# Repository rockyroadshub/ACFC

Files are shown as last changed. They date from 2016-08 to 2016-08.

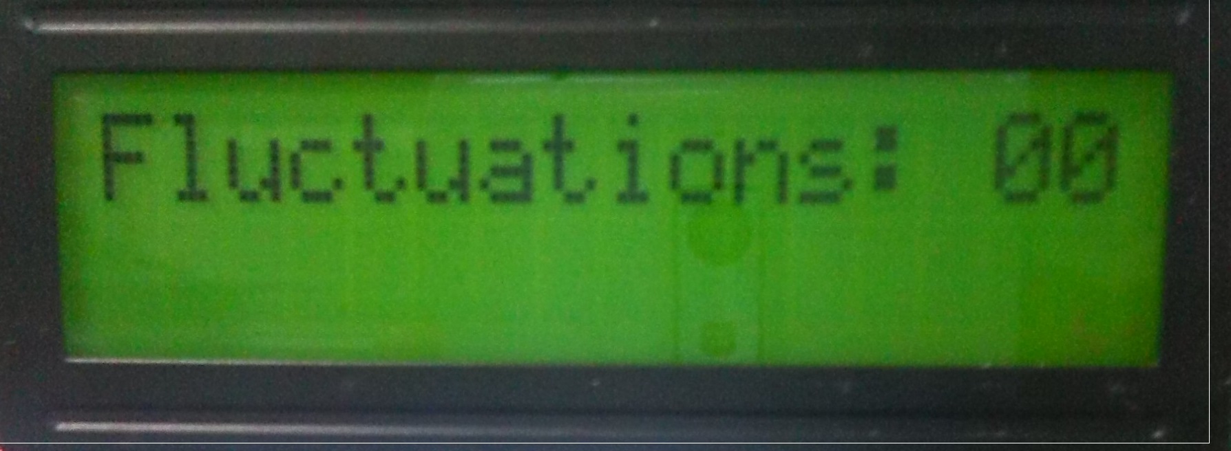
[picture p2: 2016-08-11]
Essentials/Features/Total Fluctuation Display.jpg

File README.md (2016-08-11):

# ACFC
ACFC Timer and Counter is a micro-controller based project that gets the time and 
counts the number of power outages occurred.
-------------------------------------------------------------------------------------------------
PROJECT :   AC Fluctuation TImer and Counter
VERSION :   1.0.0
FILE    :   ACFC_MAIN.ino
AUTHOR  :   Arnell Christoper D. Dalid
COMPANY :   PLDT Makati - South Core Net--Field Force 3 (PEMS) [PHILS]
PURPOSE :   [Internship Project] - Counts and save the time duration of a fluctuation occured
HISTORY :   [Created - 1.0.0]    - November 25, 2014
            [Finalized]          - March 3, 2015 (Source Code)
-------------------------------------------------------------------------------------------------          
FOLDERS										REMARKS

I.	Essentials								Important files needed to create project
	1. Features
	2. Model
	3. Others
	4. PCB
	5. Parts List

II.	Libraries								Libraries needed for the project's source code
	1. MemoryFree
	2. Misc
	3. StopWatch
	4. Time

III.Manuals									Manuals for different components used in the
	1. Source File							project
	2. ACFC Manual
	3. ACFC Report
	4. ATmega
	5. Gizduino Compatibility
	6. Gizduino Installation Guide
	7. LCD 16x2 SC162A3 Datasheet
	8. OMRON MY Relay Datasheet
	9. PCB Etching

IV.	Peripherals								Programs used for the project
	1. gizDuinoPatch
	2. PL2303 win7 installer
	3. arduino-1.0.6-windows

V.	Source Code								Code to be uploaded in the Gizduino ATmega
											microcontroller
-------------------------------------------------------------------------------------------------                                   
Other Softwares used: (freewares)

NAME		VERSION		DOWNLOAD LINK

Blender		2.73		http://www.blender.org/download/
Fritzing	0.9.1b		http://www.fritzing.org/download/

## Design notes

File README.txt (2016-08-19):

# ACFC
Copyright 2016 Arnell Christoper D. Dalid

ACFC Timer and Counter is a micro-controller based project that gets the time and 
counts the number of power outages occurred.

Licensed under GNU General Public License v3.0 (see license.txt)
-------------------------------------------------------------------------------------------------
PROJECT :   AC Fluctuation TImer and Counter
VERSION :   1.0.0
FILE    :   ACFC_MAIN.ino
AUTHOR  :   Arnell Christoper D. Dalid
COMPANY :   PLDT Makati - South Core Net--Field Force 3 (PEMS) [PHILS]
PURPOSE :   [Internship Project] - Counts and save the time duration of a fluctuation occured
HISTORY :   [Created - 1.0.0]    - November 25, 2014
            [Finalized]          - March 3, 2015 (Source Code)
-------------------------------------------------------------------------------------------------          
FOLDERS						REMARKS

I.	Essentials				Important files needed to create project
	1. Features
	2. Model
	3. Others
	4. PCB
	5. Parts List

II.	Libraries				Libraries needed for the project's source code
	1. MemoryFree
	2. Misc
	3. StopWatch
	4. Time

III.Manuals					Manuals for different components used in the
	1. Source File				project
	2. ACFC Manual
	3. ATmega
	4. Gizduino Compatibility
	5. Gizduino Installation Guide
	6. LCD 16x2 SC162A3 Datasheet
	7. OMRON MY Relay Datasheet
	8. PCB Etching

IV.	Peripherals				Programs used for the project
	1. gizDuinoPatch
	2. PL2303 win7 installer

V.	Source Code				Code to be uploaded in the Gizduino ATmega
						microcontroller
-------------------------------------------------------------------------------------------------                                   
Other Softwares used: (freewares)

NAME		VERSION		WEBSITE

Blender		2.73		http://www.blender.org
Fritzing	0.9.1b		http://www.fritzing.org
Arduino IDE	1.0.6		http://www.arduino.cc

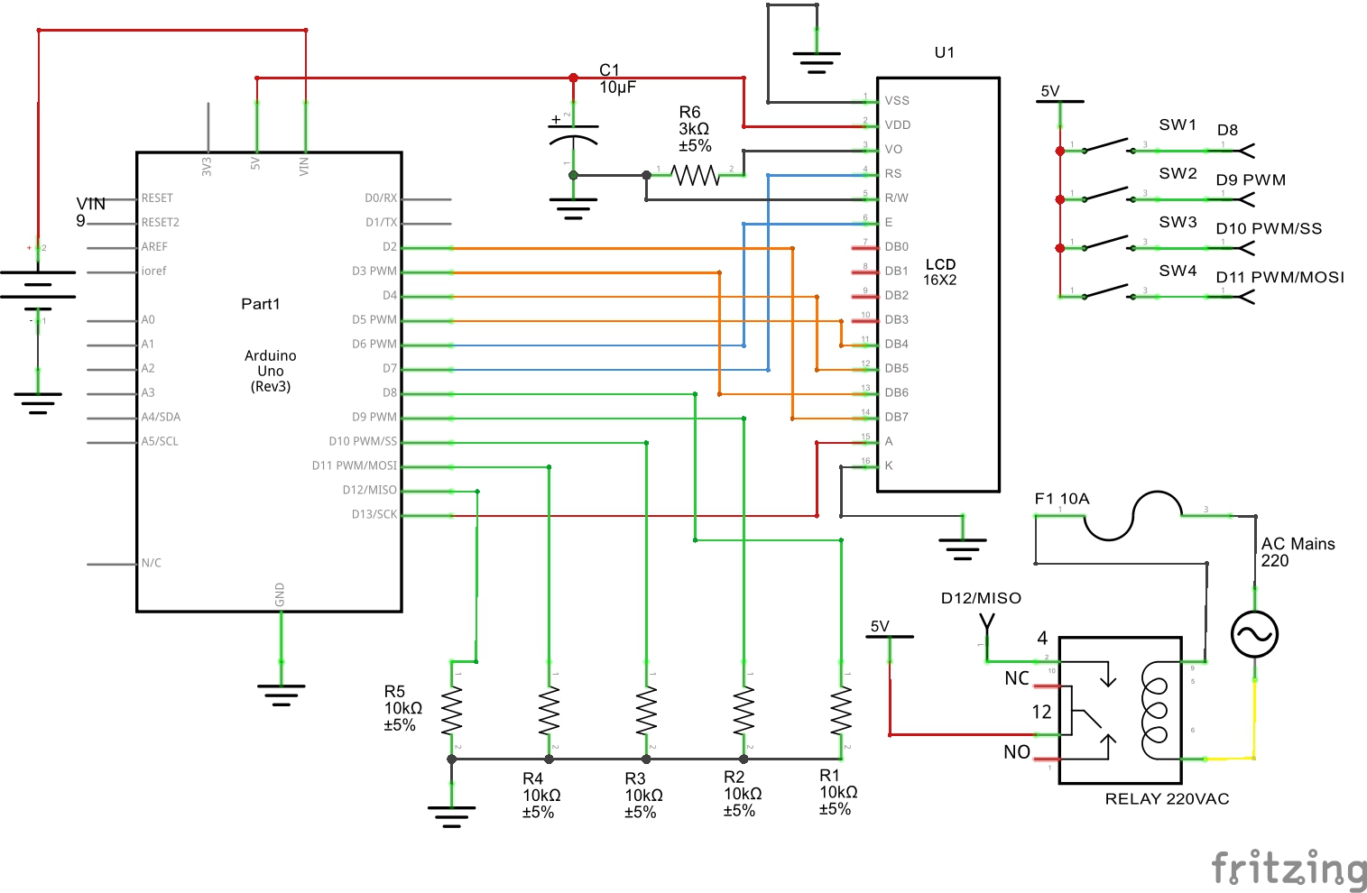
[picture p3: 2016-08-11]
Essentials/PCB/Schematic Diagram/Schematic Diagram.jpg

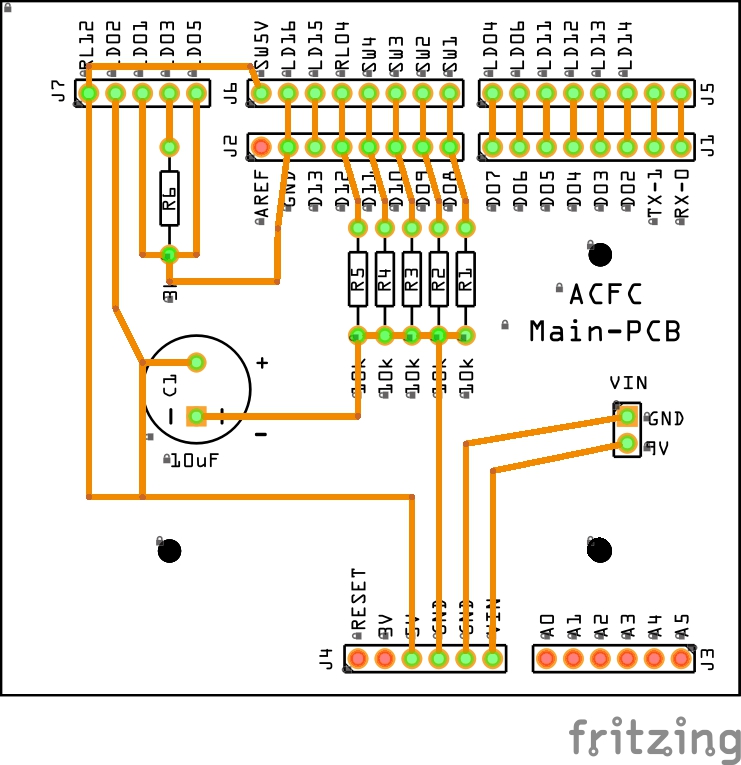
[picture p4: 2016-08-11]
Essentials/PCB/Main PCB/Main PCB Insulated Side.jpg

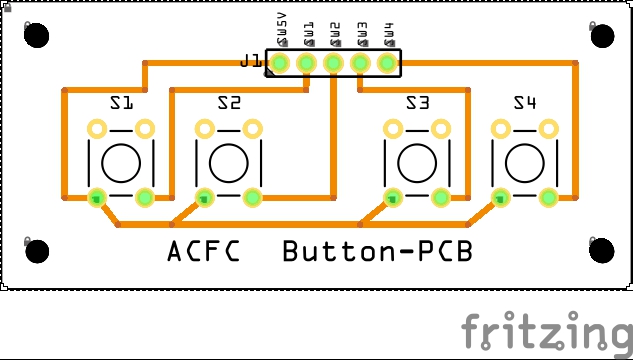
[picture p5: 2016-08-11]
Essentials/PCB/Button PCB/Button PCB Insulated Side.jpg

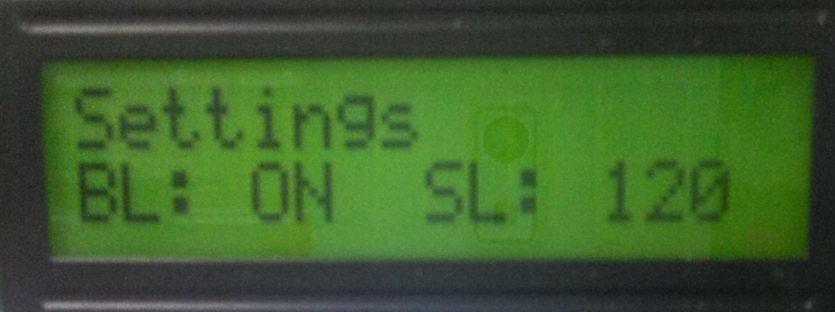
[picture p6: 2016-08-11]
Essentials/Features/Settings.jpg

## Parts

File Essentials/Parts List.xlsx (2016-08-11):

COMPONENT | PRICE | QUANTITY | TOTAL PC/COMPONENT
Gizduino ATmega328P | 662.00 | 1 | 662.00 | OTHERS
LCD 16x2 (Hitachi HD44780 Driver Compatible) | 200.00 | 1 | 200.00 | Item | Price | Quantity | Subtotal
OMRON MY-2NJ 220VAC Relay | 150.00 | 1 | 150.00 | Glossy Paper (per 20 pcs) | 50.00 | 1 | 50.00
1-PIN Female-to-Female Connector | 5.00 | 12 | 60.00 | Ferric Chloride (4 oz) | 100.00 | 1 | 100.00
4-PIN Female-to-Female Connector | 20.00 | 2 | 40.00 |  |  | TOTAL | 150.00
9V Battery Snap Connector | 5.00 | 1 | 5.00
9V Battery | 150.00 | 1 | 150.00
8-PIN Header (Female) | 2.50 | 4 | 10.00
6-PIN Header (Female) | 2.00 | 2 | 4.00
40-PIN Header (Male) | 12.50 | 1 | 12.50
5-PIN Header (Male-Long) | 0.25 | 1 | 0.25
Tact Switch | 2.50 | 4 | 10.00
Resistor 3kΩ | 0.25 | 4 | 1.00
Resistor 10kΩ | 0.25 | 5 | 1.25
Solid Wire (Quantity in meters) | 5.50 | 3 | 16.50
PCB 60x28mm | 5.00 | 1 | 5.00
PCB 66x70mm | 15.00 | 1 | 15.00
AC Power Plug | 40.00 | 1 | 40.00
Panel Mount Fuse | 10.00 | 1 | 10.00
Fuse 10A | 20.00 | 1 | 20.00
Capacitor 10uF | 5.00 | 1 | 5.00
 | TOTAL |  | 1417.50

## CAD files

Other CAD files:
Essentials/Model/ACFC.blend

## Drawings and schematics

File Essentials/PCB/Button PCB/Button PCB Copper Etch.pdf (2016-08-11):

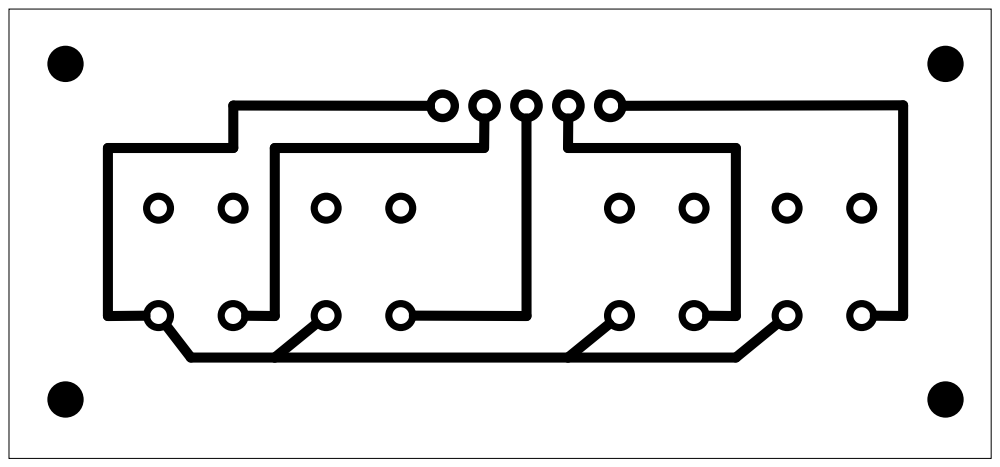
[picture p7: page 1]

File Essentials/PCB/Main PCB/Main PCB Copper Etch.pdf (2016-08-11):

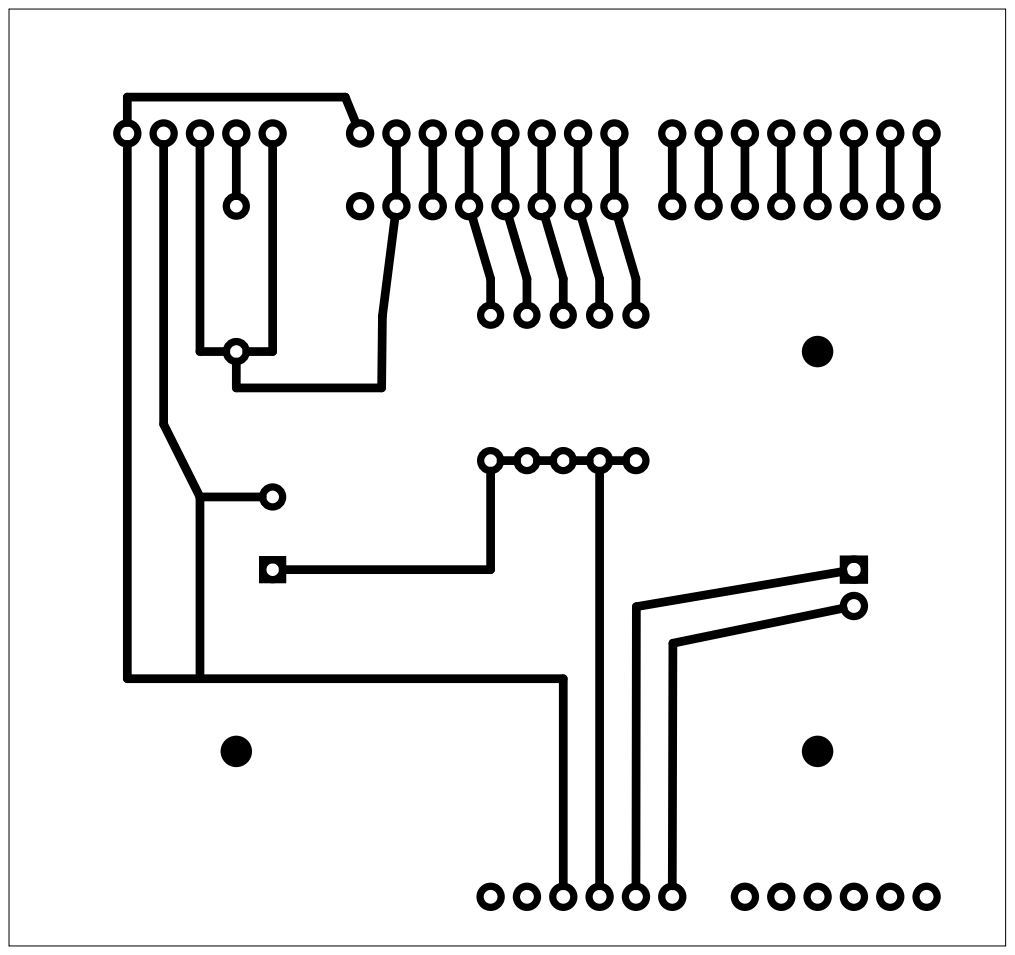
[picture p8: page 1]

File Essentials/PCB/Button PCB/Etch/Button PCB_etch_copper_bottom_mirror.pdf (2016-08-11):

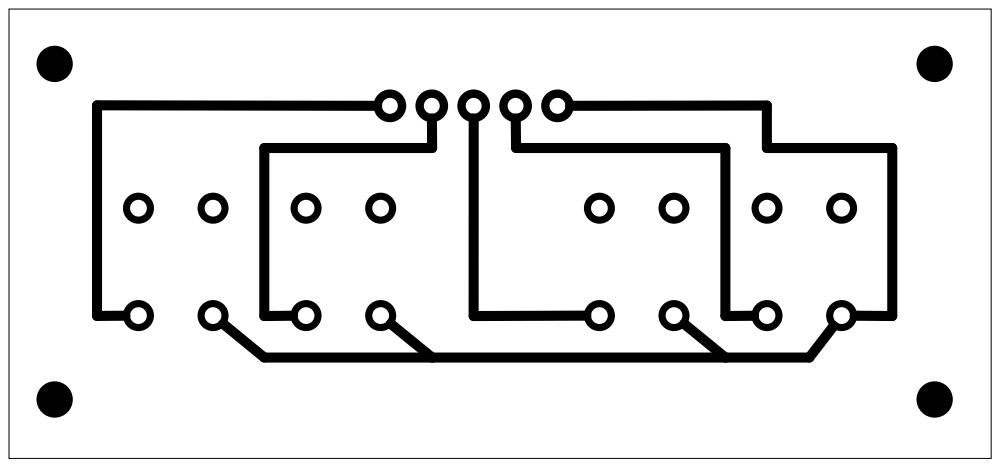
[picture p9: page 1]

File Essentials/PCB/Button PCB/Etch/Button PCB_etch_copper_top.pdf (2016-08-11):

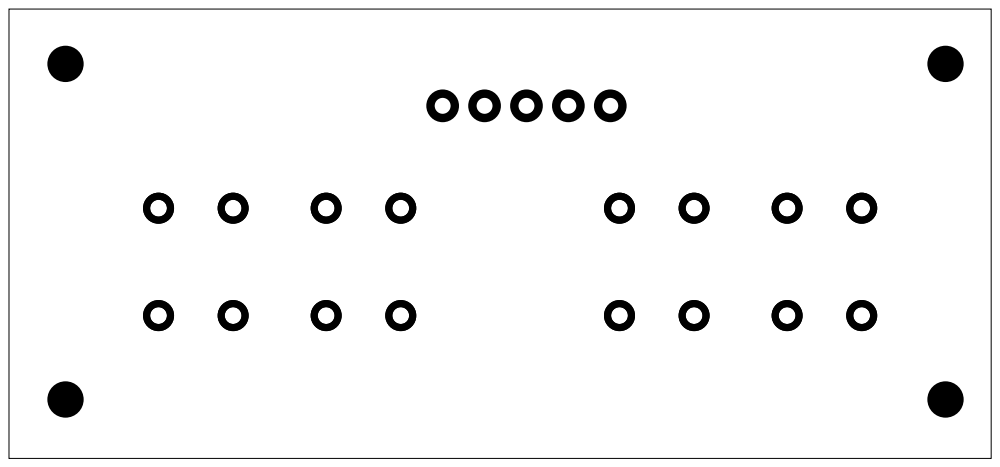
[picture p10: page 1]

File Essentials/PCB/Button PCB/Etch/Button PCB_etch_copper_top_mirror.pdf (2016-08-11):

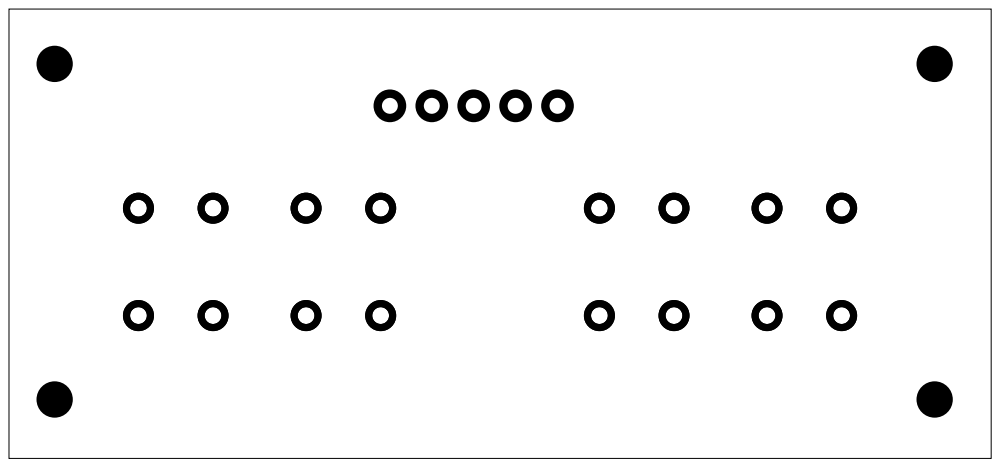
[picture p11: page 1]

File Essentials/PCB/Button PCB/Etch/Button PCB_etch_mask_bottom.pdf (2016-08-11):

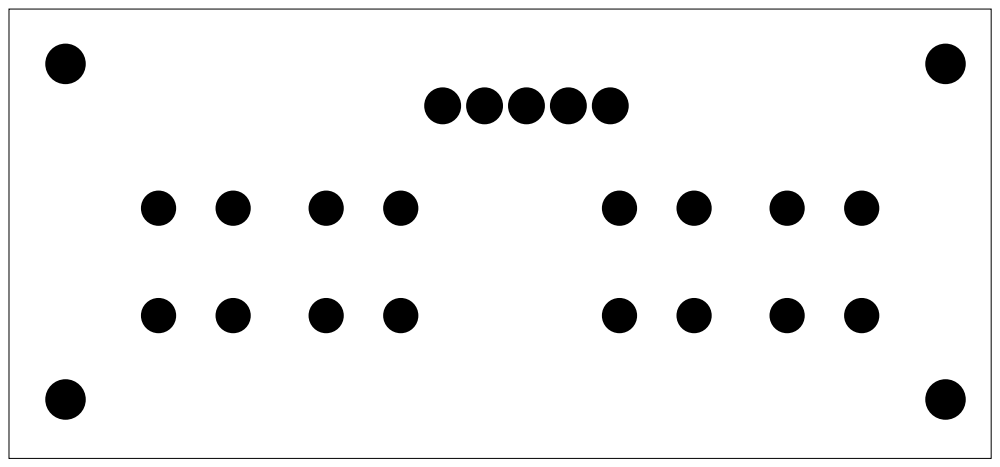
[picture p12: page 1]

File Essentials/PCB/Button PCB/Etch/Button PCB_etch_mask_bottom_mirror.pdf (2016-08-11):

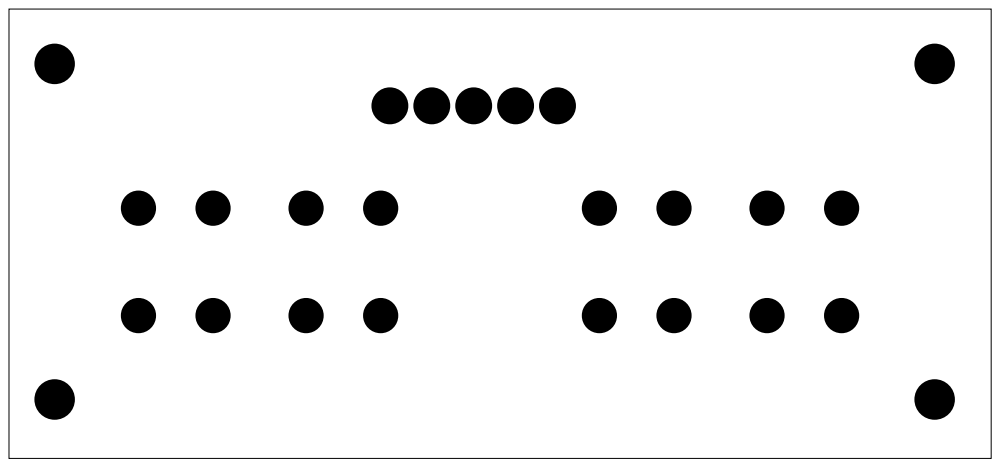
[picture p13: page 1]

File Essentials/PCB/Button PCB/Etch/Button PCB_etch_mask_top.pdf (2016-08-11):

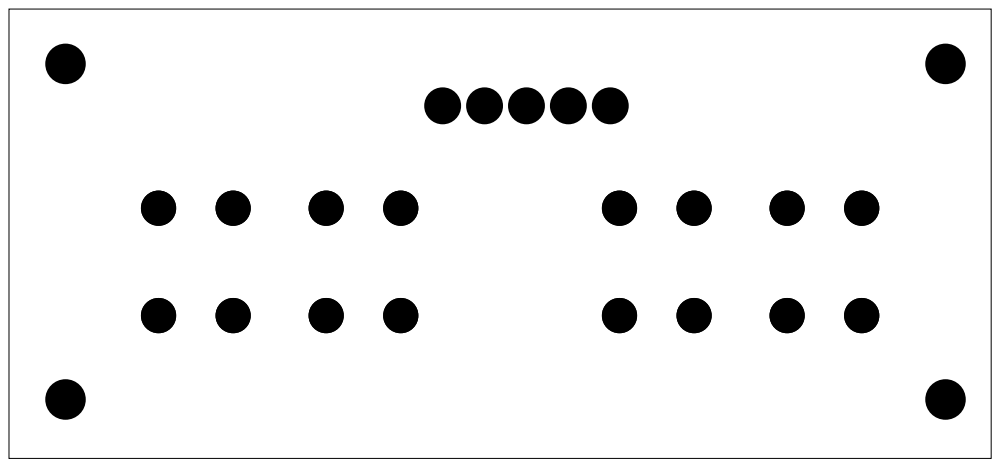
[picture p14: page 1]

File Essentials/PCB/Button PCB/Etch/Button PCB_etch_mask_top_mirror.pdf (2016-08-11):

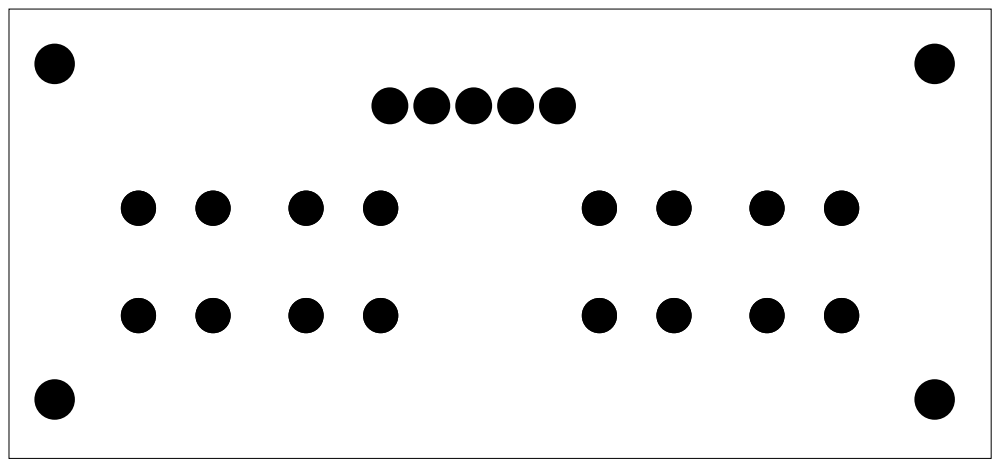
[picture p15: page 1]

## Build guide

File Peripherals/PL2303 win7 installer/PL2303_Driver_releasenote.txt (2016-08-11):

PL-2303 Driver Setup Installer, Prolific Edition
Setup Installer Revision Note History
==================================================

System Requirement:
  . Supports the following Windows OSes:
	- Windows 2000 SP4
	- Windows XP SP2 and above (32 & 64 bit)
	- Windows Server 2003 (32 & 64 bit)
	- Windows Server 2008 / 2008 R2 (32 & 64 bit)
	- Windows Vista (32 & 64 bit)
	- Windows 7 (32 & 64 bit)
  . USB host controller
  . Device using PL-2303H/HX/X version chip

Supported device ID and product strings:
  . VID_067B&PID_2303 for "Prolific USB-to-Serial Comm Port"

Driver Versions:
-------------------
	- Windows 2000/XP/Server2003 (32 & 64-bit) WDM WHQL Driver: v2.0.16.166
	- Windows Vista/7/Server2008 (32 & 64-bit) WDF WHQL Driver: v3.3.17.203

Release Notes:
---------------
PL2303 Driver Installer v1.4.17
  Changes from Installer v1.3.0:

   Installer & Build date: 1.4.17 (2011-5-24)
	GUID:ECC3713C-08A4-40E3-95F1-7D0704F1CE5E

   Windows 2000/XP/Server2003 Driver v2.0.16.166  
   ----------------------------------------------
	Driver Change from v2.0.13.130:
	. Use different service name in INF file to avoid driver conflict with Vista/7 INF driver. 
	      - change line in INF file to {Serial.SVCDESC = "Prolific Serial port WDMdriver"}
	. Added 10ms delay (downstream buffer) on close COM port to fix customer MCU application. 	
	. Added more baud rate support previously requested by customers:
		-110bps 
		-5787bps 
		-256000bps
		-56000bps
		-2Mbps
		-2.25Mbps
		-3.2Mbps
		-3333333bps
		-4Mbps
		-4.5Mbps
		-5Mbps
	 	-5333333bps
		-6.6Mbps
	    	-6.625Mbps
		-8Mbps

   Windows Vista/7/Server2008/Server2008R2 Driver Changes v3.3.17.203
   ------------------------------------------------------------------
	Driver Change from v3.3.11.152:
	. Use different service name in INF file to avoid driver conflict with XP INF driver. 
	      - change line in INF file to {Serial.SVCDESC = "Prolific Serial port WDFdriver"}
	. Added USB Selective Suspend power saving feature requested by Notebook PC vendors. 
	      - Chip will go to sleep mode when idle for 10 seconds and COM port not open. 
	      - Chip will NOT go to sleep mode when COM port is OPEN.
	. Modify "SerialUndoExternalNaming" routine.
		- Fix COM port is not removed in registry when device is unplug and program still open. 
		- update registry HKEY_LOCAL_MACHINE\HARDWARE\DEVICEMAP\SERIAL COMM when unplug and replug.
	. Added support for TransmitCommChar() function.
	. Added SpinLock function to fix customer GPS application. 
	. Added more baud rate support previously requested by customers:
		-110bps 
		-5787bps 
		-256000bps
		-56000bps
		-2Mbps
		-2.25Mbps
		-3.2Mbps
		-3333333bps
		-4Mbps
		-4.5Mbps
		-5Mbps
	 	-5333333bps
		-6.6Mbps
	    	-6.625Mbps
		-8Mbps

   Language Support: 
	- English (default)
	- Chinese (Traditional) 
	- Chinese (Simplified)
	- Japanese

========================================
Prolific Technology Inc.
http://www.prolific.com.tw

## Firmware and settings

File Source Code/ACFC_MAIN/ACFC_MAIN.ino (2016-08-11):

/*
=====================================================================================================================================
          PROJECT :   AC Fluctuation TImer and Counter
          VERSION :   1.0.0
          FILE    :   ACFC_MAIN.ino
          AUTHOR  :   Arnell Christoper D. Dalid
          COMPANY :   PLDT Makati - South Core Net--Field Force 3 (PEMS) [PHILS]
          PURPOSE :   [Internship Project] - Counts and save the time duration of a fluctuation occured
          HISTORY :   [Created - 1.0.0]    - November 25, 2014
                      [Finalized]          - March  3, 2015 (Source Code)
                      [Edited]             - March 24, 2015 Added RST_func() for Resetting data
=====================================================================================================================================
*/

/* Libraries */
// ==================================================================================================================================
#include <LiquidCrystal.h>
#include <avr/pgmspace.h>
#include <MemoryFree.h>
#include <StopWatch.h>
#include <inttypes.h>
#include <EEPROM.h>
#include <Time.h>
#include <Misc.h>
// ==================================================================================================================================

/* [A] Liquid Crystal (16x2) PINS  */
// ==================================================================================================================================
/*
 ------------------------------------------------------------------------
 | gizDuino ATmega328P PINS |  LCD 16x2 PINS (left to right)            |
 |          GND             |          01 - VSS                         |
 |          +5V             |          02 - VDD                         |
 |    w/3k Ohms Resistor    |          03 - VO  (Contrast)              |
 |          D07             |          04 - RS  (Select signal)         |
 |          GND             |          05 - R/W (Read/Write)            |
 |          D06             |          06 - E   (Enable)                |
 |          D05             |          11 - DB4 (Data bus [4-bit Mode]) |
 |          D04             |          12 - DB5      "       "          |
 |          D03             |          13 - DB6      "       "          |
 |          D02             |          14 - DB7      "       "          |
 |          D12             |          15 - A   (Backlight Power [+5v]) |
 |          GND             |          16 - K                           |
 ------------------------------------------------------------------------ 
*/

LiquidCrystal LCD(7,6,5,4,3,2);             // Liquid Crystal ( RS, E, DB4, DB5, DB6, DB7) --> 4-bit Mode
// ==================================================================================================================================

/* [0] Main System Variables */
// ==================================================================================================================================
/* [a] */
#define ACFC_VERSION "1.0.0"                // Device's current version

/* [b] */
#define RESET 0                             // For Reseting variables to 0
#define START 1                             // For Reseting variables to 1
#define PERIOD 50                           // Global device Sensitivity
#define LOCK_LOGO 0                         // Variable for calling lock-logo
#define ULCK_LOGO 1                         //     "           "    unlock-logo
#define BAUD_RATE 9600                      // Baud Rate
const uint8_t LMT  = 31;                    // Maximum Fluctuation data that can be saved
const uint8_t SEC  = 1000/PERIOD;           // Total counts to achieve 1 second (for Sleep and Edit Timer)
byte lock[8]       = {0,14,17,17,31,31,31}; // Logo for locking device
byte ulck[8]       = {0,14,16,16,31,31,31}; // "  " for unlocking device

/* [c] */
const uint8_t BFF = 4;                      // Buffer limit
char cmdBUFFER[BFF];                        // Command buffer

/* [d] */
uint8_t iFC;                                // Total Fluctuations occurred
uint8_t iBR;                                // Index for browsing functions
time_t FC[LMT];                             // Fluctuation Time Duration Storage
time_t OC[LMT];                             // Fluctuation Time/Date Storage
uint16_t SLPTimer;                          // Timer for sleep
uint16_t EDTTimer1;                         // Timer for editing System Date
uint16_t EDTTimer2;                         //    "         "    System Setting
StopWatch time_FC(StopWatch::SECONDS);      // Stopwatch Timer for a fluctuation's time duration
StopWatch time_DS(StopWatch::SECONDS);      // Stopwatch Timer for displaying data
// ==================================================================================================================================

/* [1] Pins for Keys (Input/Output) */
// ==================================================================================================================================
#define PIN_PROG 8                          // Select Display
#define PIN_MODE 9                          // Select Mode
#define PIN_INCR 10                         // Increment
#define PIN_DECR 11                         // Decrement
#define PIN_RLAY 12                         // Relay Power     (OUTPUT PIN)
#define PIN_BCKL 13                         // Backlight Power (OUTPUT PIN) 
// ==================================================================================================================================

/* [2] Address for System Settings */
// ==================================================================================================================================
#define ADDRESS_EPDEF 0                     // EEPROM Reset    (65)
#define ADDRESS_ISDEF 122                   // Default Set     (0|1)
#define ADDRESS_STBCK 123                   // Backlight State (0|1)
#define ADDRESS_STDIS 124                   // Display TImer   (1)
#define ADDRESS_STSLP 125                   // Sleep Timer     (0|255)
#define ADDRESS_STEDT 126                   // Edit Timer      (0|255)
#define ADDRESS_ISDBG 127                   // Debug Mode      (0|1)
// ==================================================================================================================================

/* [3] Default Values for Settings  */
// ==================================================================================================================================
#define DEFAULT_BCKLG LOW                   // Backlight default state
#define DEFAULT_DISPL 1                     // Display Timer (1 second refresh rate)
#define DEFAULT_EPDEF 65                    // EEPROM Reset Lock
#define DEFAULT_EDITS 30                    // Edit Time Duration (in Seconds)
#define DEFAULT_SLEEP_MIN 60                // Sleep Timer - Min     "    "
#define DEFAULT_SLEEP_MAX 120               // Sleep Timer - Max     "    "
#define DEFAULT_DEBUG false                 // Debug state
// ==================================================================================================================================

/* [4] Variable Settings */
// ==================================================================================================================================
uint8_t BCK;                                // Variable for loading Backlight state (ON/OFF)
uint8_t DIS;                                //       "         "    Display
uint8_t SLP;                                //       "         "    Sleep Timer
uint8_t EDT;                                //       "         "    Edit Time Duration (System Date and Setting)
boolean isDBG;                              // Trigger for Debug Mode
boolean isRLY;                              // Relay Switch debounce
// ==================================================================================================================================

/* [5] Main Program Variables and Constants */
// ==================================================================================================================================
#define PROG_TIMER_FDATE_DISP 1             // Displays TIME,DATE & DURATION of a fluctuation occured 
#define PROG_TOTAL_COUNT_DISP 2             //   " "    COUNT of fluctuations
#define PROG_SYSTEM_DATE_DISP 3             //   " "    SYSTEM DATE
#define PROG_SYSTEM_STNG_DISP 4             //   " "    SYSTEM SETTINGS (LCD Contrast, Sleep Mode, Backlight)
#define PROG_SYSTEM_DEBUG_MOD 5             // Puts the device on debug mode
#define PROG_SYSTEM_INTR_LOCK 6             // Mode of program for LOCKING the device, disabling it from controlling unless, unlocked
uint8_t modePROG;                           // Mode counter for determining what program to be used and display
// ==================================================================================================================================

/* [6] System Date Variables and Constants */
// ==================================================================================================================================
#define SYSTEM_DATE_MT 1                    // Month Setting Mode
#define SYSTEM_DATE_DY 2                    // Day      " "
#define SYSTEM_DATE_YR 3                    // Year     " "
#define SYSTEM_DATE_HR 4                    // Hour     " "
#define SYSTEM_DATE_MN 5                    // Minute   " "
#define SYSTEM_DATE_SC 6                    // Second   " "
#define SYSTEM_DATE_ED 7                    // System Date Setting OFF
uint8_t modeSYSD;                           // Mode counter for the editing time & date in SYSTEM DATE
uint8_t sysdEDIT;                           // Mode counter for editing each items in SYSTEM DATE
// ==================================================================================================================================

/* [7] System Setting Variables and Constants */
// ==================================================================================================================================
#define SETTING_CONFIG_BCK 1                // Backlight Setting Mode
#define SETTING_CONFIG_SLP 2                // Sleep Setting Mode
#define SETTING_CONFIG_EDT 3                // Setting Mode OFF
uint8_t modeSTNG;                           // Mode counter for the editing time SETTINGS
uint8_t stngEDIT;                           // Mode counter for editing each items in SETTINGS
// ==================================================================================================================================

/* [8] System Keys Variables */
// ==================================================================================================================================
Button SW1 (PIN_PROG, RUN_ONCE);            // Select Display (Program)
Button SW2 (PIN_MODE, RUN_ONCE);            // Select Mode - for editing date and settings)
Button SW3 (PIN_INCR, RUN_ONCE);            // Increment       " "
Button SW4 (PIN_DECR, RUN_ONCE);            // Decrement       " "
Button LCK (PIN_PROG, PIN_MODE, RUN_ONCE);  // System Lock
Button CLR (PIN_PROG, PIN_INCR, RUN_ONCE);  // Clear/Reset Display
Button RST (PIN_PROG, PIN_DECR, RUN_ONCE);  // Resets data
// ==================================================================================================================================

/* [9] Month Variables */
// ==================================================================================================================================
#define IS_MONTH_JAN (__DATE__[0] == 'J' && __DATE__[1] == 'a' && __DATE__[2] == 'n')  // January
#define IS_MONTH_FEB (__DATE__[0] == 'F' && __DATE__[1] == 'e' && __DATE__[2] == 'b')  // February
#define IS_MONTH_MAR (__DATE__[0] == 'M' && __DATE__[1] == 'a' && __DATE__[2] == 'r')  // March
#define IS_MONTH_APR (__DATE__[0] == 'A' && __DATE__[1] == 'p' && __DATE__[2] == 'r')  // April
#define IS_MONTH_MAY (__DATE__[0] == 'M' && __DATE__[1] == 'a' && __DATE__[2] == 'y')  // May
#define IS_MONTH_JUN (__DATE__[0] == 'J' && __DATE__[1] == 'u' && __DATE__[2] == 'n')  // June
#define IS_MONTH_JUL (__DATE__[0] == 'J' && __DATE__[1] == 'u' && __DATE__[2] == 'l')  // July
#define IS_MONTH_AUG (__DATE__[0] == 'A' && __DATE__[1] == 'u' && __DATE__[2] == 'g')  // August
#define IS_MONTH_SEP (__DATE__[0] == 'S' && __DATE__[1] == 'e' && __DATE__[2] == 'p')  // September
#define IS_MONTH_OCT (__DATE__[0] == 'O' && __DATE__[1] == 'c' && __DATE__[2] == 't')  // October
#define IS_MONTH_NOV (__DATE__[0] == 'N' && __DATE__[1] == 'o' && __DATE__[2] == 'v')  // November
#define IS_MONTH_DEC (__DATE__[0] == 'D' && __DATE__[1] == 'e' && __DATE__[2] == 'c')  // December
// ==================================================================================================================================

/* [10] Serial Commands Variables */
// ==================================================================================================================================
#define IS_RST (cmdBUFFER[0] == '-' && cmdBUFFER[1] == 'R' && cmdBUFFER[2] == 'S' && cmdBUFFER[3] == 'T')  // -RST --> Reset EEPROM
#define IS_DBG (cmdBUFFER[0] == '-' && cmdBUFFER[1] == 'D' && cmdBUFFER[2] == 'B' && cmdBUFFER[3] == 'G')  // -DBG --> Set to Debug
#define IS_MEM (cmdBUFFER[0] == '-' && cmdBUFFER[1] == 'M' && cmdBUFFER[2] == 'E' && cmdBUFFER[3] == 'M')  // -MEM --> Check SRAM
#define ST_BCK (cmdBUFFER[0] == '-' && cmdBUFFER[1] == 'B' && cmdBUFFER[2] == 'L')                         // -BLX --> Set Backlight
#define ST_BL0 (cmdBUFFER[3] == '0')                                                                       //   0  --> Set BCK OFF
#define ST_BL1 (cmdBUFFER[3] == '1')                                                                       //   1  --> Set BCK ON
#define CK_INF (cmdBUFFER[0] == '-' && cmdBUFFER[1] == 'I' && cmdBUFFER[2] == 'N' && cmdBUFFER[3] == 'F')  // -INF --> Check Info
#define ST_DEF (cmdBUFFER[0] == '-' && cmdBUFFER[1] == 'D' && cmdBUFFER[2] == 'E' && cmdBUFFER[3] == 'F')  // -DEF --> Set to default
#define ST_SLP (cmdBUFFER[0] == '-' && cmdBUFFER[1] == 'S' && cmdBUFFER[2] == 'L' && cmdBUFFER[3] == 'P')  /* -SLP --> Sets Sleep 
                                                                                                               3-DIGIT Format
                                                                                                               e.g. -SLP 050 
                                                                                                               sets to 50 seconds
                                                                                                           */
#define ST_EDT (cmdBUFFER[0] == '-' && cmdBUFFER[1] == 'E' && cmdBUFFER[2] == 'D' && cmdBUFFER[3] == 'T') /* -EDT --> Sets Edit
                                                                                                             3-DIGIT Format
                                                                                                             e.g.  -EDT 050
                                                                                                             sets to 50 seconds
                                                                                                          */
boolean isST_SLP, isST_EDT;   // boolean for editing date/settings and sleep timer                                                                                                        
// ==================================================================================================================================

/* [11] Serial Message Variables */
// ==================================================================================================================================
const uint8_t mBFF = 35;
char msgBUFFER[mBFF];
const char M00[] PROGMEM = "Version         : ";                         // 0
const char M01[] PROGMEM = "Date Compiled   : ";                         // 1
const char M02[] PROGMEM = "Timer/Delays (sec)";                         // 2
const char M03[] PROGMEM = "Period (milli)  : ";                         // 3
const char M04[] PROGMEM = "Backlight State : ";                         // 4
const char M05[] PROGMEM = "Sleep           : ";                         // 5
const char M06[] PROGMEM = "Edit Settings   : ";                         // 6
const char M07[] PROGMEM = "Display Refresh : ";                         // 7
const char M08[] PROGMEM = "Booleans (0|1)    ";                         // 8
const char M09[] PROGMEM = "Debug State     : ";                         // 9
const char M10[] PROGMEM = "Is Default set  : ";                         // 10
const char M11[] PROGMEM = "Available SRAM  : ";                         // 11
const char M12[] PROGMEM = "EEPROM reset. Please reset device";          // 12
const char M13[] PROGMEM = "Backlight set to: ";                         // 13
const char M14[] PROGMEM = "Debug ";                                     // 14
const char M15[] PROGMEM = "enabled";                                    // 15
const char M16[] PROGMEM = "disabled";                                   // 16
const char M17[] PROGMEM = "ON";                                         // 17
const char M18[] PROGMEM = "OFF";                                        // 18
const char M19[] PROGMEM = "Sleep set to: ";                             // 19
const char M20[] PROGMEM = "Edit set to: ";                              // 20
const char M21[] PROGMEM = "Defaults set.";                              // 21
const char M22[] PROGMEM = "Clearing address: ";                         // 22
const char M23[] PROGMEM = "Clearing done.";                             // 23
const char M24[] PROGMEM = "Setting defaults..";                         // 24
const char M25[] PROGMEM = "Loading settings..";                         // 25
const char M26[] PROGMEM = "Settings loaded.";                           // 26
const char M27[] PROGMEM = "Device ready.";                              // 27

/* [a] Message Table */
const char* const MSG_TABLE[] PROGMEM = { M00, M01, M02, M03, M04, M05, M06, M07, M08, M09, M10,
                                          M11, M12, M13, M14, M15, M16, M17, M18, M19, M20, M21, 
                                          M22, M23, M24, M25, M26, M27 };
// ==================================================================================================================================

// ==================================================================================================================================
// NOTE: Only Variable Sets A, 1 and 3 can be altered. Editing other variables might make the system unstable.
// ==================================================================================================================================

void setup () {
  systemInit();
}

void loop () {
  delay(PERIOD);
  systemFunc();
  
  if (SW1.pressed() && modePROG != PROG_SYSTEM_INTR_LOCK) { SW1_func(); }
  else if (SW2.pressed() && modePROG != RESET && modePROG != PROG_SYSTEM_INTR_LOCK) { SW2_func(); }
  else if (SW3.pressed() && modePROG != RESET && modePROG != PROG_SYSTEM_INTR_LOCK) { SW3_func(); }
  else if (SW4.pressed() && modePROG != RESET && modePROG != PROG_SYSTEM_INTR_LOCK) { SW4_func(); }
  else if (LCK.pressed2()) { LCK_func(); } 
  else if (CLR.pressed2()) { CLR_func(); }
  else if (RST.pressed2()) { RST_func(); }
}

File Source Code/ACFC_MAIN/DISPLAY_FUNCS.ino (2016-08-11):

void digitDisp (uint16_t i, uint8_t c, uint8_t r, uint8_t d) {
  boolean isZero=false;
  uint8_t count = 0;
  uint16_t num = i;
  while (!isZero) {
    i /= 10;
    count++;
    if (i==0) { isZero=true; }
  }
  uint8_t total = d-count;
  LCD.setCursor(c,r);
  for (uint8_t j=0; j < total; j++) { LCD.print("0"); }
  LCD.print(num);
}

void dispDate (time_t t, uint8_t c, uint8_t r) {
  uint8_t _year = 0;
  if (year(t) >= 2000) { _year = year(t) - 2000; }
  digitDisp(month(t),c,r,2);
  digitDisp(day(t),c+2,r,2);
  digitDisp(_year,c+4,r,2);
  digitDisp(hour(t),c+7,r,2);
  digitDisp(minute(t),c+10,r,2);
  digitDisp(second(t),c+13,r,2);
}

void dispBCKState () {
  if (BCK) { LCD.setCursor(4,1); LCD.print("ON "); }
  else { LCD.setCursor(4,1); LCD.print("OFF"); }
}

void dispData () {
  switch (modePROG) {
    case PROG_TIMER_FDATE_DISP: if (iFC > 0 && iBR == iFC) { PROG_FDATE_data(iFC,iFC); } break;
    case PROG_SYSTEM_DATE_DISP: if (!modeSYSD) { PROG_DATE_data(); } break;
  }
}
